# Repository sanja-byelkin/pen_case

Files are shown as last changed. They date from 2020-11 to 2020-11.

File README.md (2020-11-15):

# pen_case
OpenSCAD parametric pen case

I broke my favorite pen in my bag, so decided to make individual pen cases for my best pens.

This project create pen case by your description. If you unsure use the customizer in OpenSCAD.

You will need this library for threads to build it https://dkprojects.net/openscad-threads/ . Put it one level up or fix very first "include" derective.

For more details see manual.html ( https://htmlpreview.github.io/?https://github.com/sanja-byelkin/pen_case/blob/main/manual.html ).

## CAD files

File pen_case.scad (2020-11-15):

include <../threads.scad>

/* [Print Settings] */
// Cyrcles interpolation
FINESS=80; //[50:500]
// Tollerance of the printer (width of cuts and increasing goven dimentions)
TOLLERANCE= 0.3; // [0.1, 0.2, 0.3, 0.4, 0.5]
// nozzle diameter
NOZZEL_D= 0.4; // [0.2, 0.3, 0.4, 0.5, 0.6, 0.7, 0.8, 0.9, 1]
//Build case or pen "models"
PRESENT="case"; // ["case","model"]
//PRESENT="model";

/* [Case] */
// Minimum Case length (0 - automatic)
CASE_MIN_LENGTH= 0;
// Minimum case "diameter" (0 - automatic)
CASE_MIN_D= 0;
// Minimum thickness of top and bottom
CASE_TOP_BOTTOM_WALL_MIN= 1.6;
// Thikness of side walls
CASE_WALL= 1.2; // [3, 2.4, 2, 1.8, 1.6, 1.2]
// Latch pin hight
LATCH_PIN_H= 2; // [3, 2.4, 2, 1.8, 1.6, 1.2]
// Latch hight
LATCH_H= 2.4; // [3, 2.4, 2, 1.8, 1.6, 1.2]
// Latch final depth (starts with thikness of the case wall)
LATCH_DEPTH= 2.4; // [3, 2.4, 2, 1.8, 1.6, 1.2]
// Case close in turns
CASE_TURN= 2/3; // [0.3333333, 0.6666666, 0.5, 1, 1.5, 2, 3]
// Case thread width
CASE_TR_W= 2.5; // [2.5, 3, 3.5, 4, 4.5, 5]
// Case thread length (not 0 - automatic length and multiplier)
CASE_TR_L= 0; // [0:100]
// Case faces
CASE_N= 3; // [3, 4, 5, 6, 7, 8, 9, 10]
// Case corners rounding
CASE_ROUNDING= 9; // [0, 1, 1.5, 2, 2.5, 3, 4, 5, 6, 8, 9, 10, 11, 12]
// Case corners rounding mode
CASE_ROUNDING_MODE="2.5d"; // ["sharp", "2d", "3d", "2.5d"]
// Case thread starts multiplier (starts = faces*multiplier)
CASE_TR_NN= 1; // [1, 2, 3, 4]
// Case thread space multiplier (as above but space)
CASE_TR_SPACE_RATIO= 1.5; // [1, 1.3333333, 1.5, 1.6666666, 2]
// So many pen will be wisible from the case to take it out
CASE_TAKE= 9;
// Latch maximum length
LATCH_MAX_L= 15;
// Generate latch supports
LATCH_SUPPORT= true;

/* [text] */
// Vertical text (empty string to no text)
VTEXT_TEXT= "Noodler's Boston Safety";
// Vertical text font
VTEXT_FONT= "Liberation Sans;style=bold";
// Vertical text size
VTEXT_SIZE= 7.8;
// Vertical text depth
VTEXT_DEPTH= 0.6;
// Vertical text skip ratio (1-each face, 2-each second ...)
VTEXT_RATIO= 1; // [1, 2, 3, 4, 5, 6, 7, 8, 9, 10]
// Vertical text turn (top-bottom / bottom-top)
VTEXT_TURN=false; // [true, false]
// Top/bottom text (empty string to no text)
TBTEXT_TEXT= "Boston";
// Top/bottom text font
TBTEXT_FONT= "Liberation Sans;style=bold";
// Top/bottom text size
TBTEXT_SIZE= 6;
// Top/bottom text turn angle
TBTEXT_ANGLE= 30;
// Top/bottom text depth
TBTEXT_DEPTH= 0.6;

/* [Pen] */

// First (top) cylinder diameter
PEN_1_D=12.5;
// First cylinder length (0 - no section)
PEN_1_L=8.2;
// First clip overhang (0 - no clip)
PEN_1_CLIP_DD=0;
// First clip width
PEN_1_CLIP_W=0;
// Second cylinder diameter
PEN_2_D=13;
// Second cylinder length (0 - no section)
PEN_2_L=40;
// Second clip overhang (0 - no clip)
PEN_2_CLIP_DD=4;
// Second clip width
PEN_2_CLIP_W=6;
// Third cylinder diameter
PEN_3_D=13;
// Third cylinder length (0 - no section)
PEN_3_L=2.5;
// Third clip overhang (0 - no clip)
PEN_3_CLIP_DD=0;
// Third clip width
PEN_3_CLIP_W=0;
// Fourth cylinder diameter
PEN_4_D=11;
// Fourth cylinder length (0 - no section)
PEN_4_L=36;
// Fourth clip overhang (0 - no clip)
PEN_4_CLIP_DD=0;
// Fourth clip width
PEN_4_CLIP_W=0;
// Fifth cylinder diameter
PEN_5_D=13;
// Fifth cylinder length (0 - no section)
PEN_5_L=56.5;
// Fifth clip overhang (0 - no clip)
PEN_5_CLIP_DD=0;
// Fifth clip width
PEN_5_CLIP_W=0;
// Sixth cylinder diameter
PEN_6_D=11;
// Sexth cylinder length (0 - no section)
PEN_6_L=12;
// Sexth clip overhang (0 - no clip)
PEN_6_CLIP_DD=0;
// Fexth clip width
PEN_6_CLIP_W=0;


/* [Hidden] */

LATCH_W= CASE_WALL;
$fn= FINESS;

/*******************************
    Some known pen model data
********************************/
/*
// Lamy 2000
// First (top) cylinder diameter
PEN_1_D=10;
// First cylinder length (0 - no section)
PEN_1_L=3.3;
// First clip overhang (0 - no clip)
PEN_1_CLIP_DD=0;
// First clip width
PEN_1_CLIP_W=0;
// Second cylinder diameter
PEN_2_D=13.6;
// Second cylinder length (0 - no section)
PEN_2_L=38.3;
// Second clip overhang (0 - no clip)
PEN_2_CLIP_DD=2.8;
// Second clip width
PEN_2_CLIP_W=5.1;
// Third cylinder diameter
PEN_3_D=14.3;
// Third cylinder length (0 - no section)
PEN_3_L=22.8;
// Third clip overhang (0 - no clip)
PEN_3_CLIP_DD=0;
// Third clip width
PEN_3_CLIP_W=0;
// Fourth cylinder diameter
PEN_4_D=13.3;
// Fourth cylinder length (0 - no section)
PEN_4_L=74.4;
// Fourth clip overhang (0 - no clip)
PEN_4_CLIP_DD=0;
// Fourth clip width
PEN_4_CLIP_W=0;
// Fifth cylinder diameter
PEN_5_D=0;
// Fifth cylinder length (0 - no section)
PEN_5_L=0;
// Fifth clip overhang (0 - no clip)
PEN_5_CLIP_DD=0;
// Fifth clip width
PEN_5_CLIP_W=0;
// Sixth cylinder diameter
PEN_6_D=0;
// Sexth cylinder length (0 - no section)
PEN_6_L=0;
// Sexth clip overhang (0 - no clip)
PEN_6_CLIP_DD=0;
// Fexth clip width
PEN_6_CLIP_W=0;
*/
/*
// Lamy Safari
// First (top) cylinder diameter
PEN_1_D=13;
// First cylinder length (0 - no section)
PEN_1_L=3.5;
// First clip overhang (0 - no clip)
PEN_1_CLIP_DD=0;
// First clip width
PEN_1_CLIP_W=0;
// Second cylinder diameter
PEN_2_D=14.7;
// Second cylinder length (0 - no section)
PEN_2_L=56.4;
// Second clip overhang (0 - no clip)
PEN_2_CLIP_DD=4;
// Second clip width
PEN_2_CLIP_W=13.5;
// Third cylinder diameter
PEN_3_D=14.7;
// Third cylinder length (0 - no section)
PEN_3_L=5.5;
// Third clip overhang (0 - no clip)
PEN_3_CLIP_DD=0;
// Third clip width
PEN_3_CLIP_W=0;
// Fourth cylinder diameter
PEN_4_D=12.5;
// Fourth cylinder length (0 - no section)
PEN_4_L=73;
// Fourth clip overhang (0 - no clip)
PEN_4_CLIP_DD=0;
// Fourth clip width
PEN_4_CLIP_W=0;
// Fifth cylinder diameter
PEN_5_D=11.7;
// Fifth cylinder length (0 - no section)
PEN_5_L=1.6;
// Fifth clip overhang (0 - no clip)
PEN_5_CLIP_DD=0;
// Fifth clip width
PEN_5_CLIP_W=0;
// Sixth cylinder diameter
PEN_6_D=0;
// Sexth cylinder length (0 - no section)
PEN_6_L=0;
// Sexth clip overhang (0 - no clip)
PEN_6_CLIP_DD=0;
// Fexth clip width
PEN_6_CLIP_W=0;
*/
/*
// Opus 88 KOLORO DEMO
// First (top) cylinder diameter
PEN_1_D=16.3;
// First cylinder length (0 - no section)
PEN_1_L=7.7;
// First clip overhang (0 - no clip)
PEN_1_CLIP_DD=0;
// First clip width
PEN_1_CLIP_W=0;
// Second cylinder diameter
PEN_2_D=16.5;
// Second cylinder length (0 - no section)
PEN_2_L=42.3;
// Second clip overhang (0 - no clip)
PEN_2_CLIP_DD=4.8;
// Second clip width
PEN_2_CLIP_W=8;
// Third cylinder diameter
PEN_3_D=16.5;
// Third cylinder length (0 - no section)
PEN_3_L=13.5;
// Third clip overhang (0 - no clip)
PEN_3_CLIP_DD=0;
// Third clip width
PEN_3_CLIP_W=0;
// Fourth cylinder diameter
PEN_4_D=15;
// Fourth cylinder length (0 - no section)
PEN_4_L=83.3;
// Fourth clip overhang (0 - no clip)
PEN_4_CLIP_DD=0;
// Fourth clip width
PEN_4_CLIP_W=0;
// Fifth cylinder diameter
PEN_5_D=0;
// Fifth cylinder length (0 - no section)
PEN_5_L=0;
// Fifth clip overhang (0 - no clip)
PEN_5_CLIP_DD=0;
// Fifth clip width
PEN_5_CLIP_W=0;
// Sixth cylinder diameter
PEN_6_D=0;
// Sexth cylinder length (0 - no section)
PEN_6_L=0;
// Sexth clip overhang (0 - no clip)
PEN_6_CLIP_DD=0;
// Fexth clip width
PEN_6_CLIP_W=0;
*/
/*
// Noodler's Konrad
// First (top) cylinder diameter
PEN_1_D=12;
// First cylinder length (0 - no section)
PEN_1_L=6.9;
// First clip overhang (0 - no clip)
PEN_1_CLIP_DD=0;
// First clip width
PEN_1_CLIP_W=0;
// Second cylinder diameter
PEN_2_D=14;
// Second cylinder length (0 - no section)
PEN_2_L=39.1;
// Second clip overhang (0 - no clip)
PEN_2_CLIP_DD=4;
// Second clip width
PEN_2_CLIP_W=6;
// Third cylinder diameter
PEN_3_D=14.5;
// Third cylinder length (0 - no section)
PEN_3_L=13;
// Third clip overhang (0 - no clip)
PEN_3_CLIP_DD=0;
// Third clip width
PEN_3_CLIP_W=0;
// Fourth cylinder diameter
PEN_4_D=12;
// Fourth cylinder length (0 - no section)
PEN_4_L=74;
// Fourth clip overhang (0 - no clip)
PEN_4_CLIP_DD=0;
// Fourth clip width
PEN_4_CLIP_W=0;
// Fifth cylinder diameter
PEN_5_D=0;
// Fifth cylinder length (0 - no section)
PEN_5_L=0;
// Fifth clip overhang (0 - no clip)
PEN_5_CLIP_DD=0;
// Fifth clip width
PEN_5_CLIP_W=0;
// Sixth cylinder diameter
PEN_6_D=0;
// Sexth cylinder length (0 - no section)
PEN_6_L=0;
// Sexth clip overhang
PEN_6_CLIP_DD=0;
// Fexth clip width
PEN_6_CLIP_W=0;
*/
/*
// Noodler's Ahab
// First (top) cylinder diameter
PEN_1_D=11;
// First cylinder length (0 - no section)
PEN_1_L=6.5;
// First clip overhang (0 - no clip)
PEN_1_CLIP_DD=0;
// First clip width
PEN_1_CLIP_W=0;
// Second cylinder diameter
PEN_2_D=15.1;
// Second cylinder length (0 - no section)
PEN_2_L=41.5;
// Second clip overhang (0 - no clip)
PEN_2_CLIP_DD=5.5;
// Second clip width
PEN_2_CLIP_W=8;
// Third cylinder diameter
PEN_3_D=15.2;
// Third cylinder length (0 - no section)
PEN_3_L=12;
// Third clip overhang (0 - no clip)
PEN_3_CLIP_DD=0;
// Third clip width
PEN_3_CLIP_W=0;
// Fourth cylinder diameter
PEN_4_D=14;
// Fourth cylinder length (0 - no section)
PEN_4_L=69.2;
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

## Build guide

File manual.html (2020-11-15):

# Installation

1. Install (if not done) OpenSCAD (https://www.openscad.org/)
2. Clone this repository or copy pen_case.scad in a directory pen_case
3. Copy from https://dkprojects.net/openscad-threads/ threads.scad in a directory above pen_case.

# Creating a pen case

You can use OpenSCAD customizer or just change variables at the beginning of the pen_case.scad manually if OpenSCAD editor (or any other text editor).

## Print settings

FINESS

How many faces will have cylinder approximation. More mean smoother model but longer render time (50-80 is enough for useful cases).

TOLLERANCE

A "gap" between real and printed object. depends on 3d printer quality and printing speed

NOZZEL_D

Diameter of your printer nozzel, now used only to print latch support.

PRESENT

Build pen "case" or pen "model".

## Case parameters

CASE_MIN_LENGTH and CASE_MIN_D

You can use non 0 values if you want to build same size cases for different pens.

CASE_TOP_BOTTOM_WALL_MIN and CASE_WALL

Minimal thickness of the walls.

LATCH_PIN_H

Lutch pin hight. 2.4-1.6 looks the best values

LATCH_H and LATCH_DEPTH

Lutch hand parameters (hight and depth). I do not recommend use LATCH_H bigger then LATCH_DEPTH and both less then 1.6 and more then 3. Top of the hand will be CASE_WALL depth and LATCH_DEPTH will not be less then CASE_WALL.

CASE_TURN

How many turns minimum needed to open this case.

CASE_TR_W

Width of the case thread.

CASE_TR_L

(Minimum) length of the case thread. If 0 will be calculated automatically

CASE_N

Number of faces of this case. Also it is minimum number of thread starts

CASE_ROUNDING

Radius of case rounding. Used if CASE_ROUNDING_MODE is not "sharp"

CASE_ROUNDING_MODE

"sharp"

No roundings.

"2d"

Only side walls.

"3d"

Side walls top and bottom (difficult to print).

"2.5d"

Side walls with CASE_ROUNDING radius and top and bottom with CASE_WALL.

CASE_TR_NN

How many thread starts do per "face". If it is not 1 can be difficult to close case correctly.

CASE_TR_SPACE_RATIO

1 mean as dense thread is possible, more then 1 makes spaces in threads. With small number of faces can be used to make longer and "steeper" thread.

CASE_TAKE

How much pen you will see after opening this case. Depend on how much you need to take the pen from the case.

LATCH_MAX_L

Max latch length, used to limit length and keep the latches stiff.

LATCH_SUPPORT

Construct or not the latches support for 3D printer

## Text setup

Probably fonts and its sizes depend on a computer setup, so just experiment.

## Pen "model" description

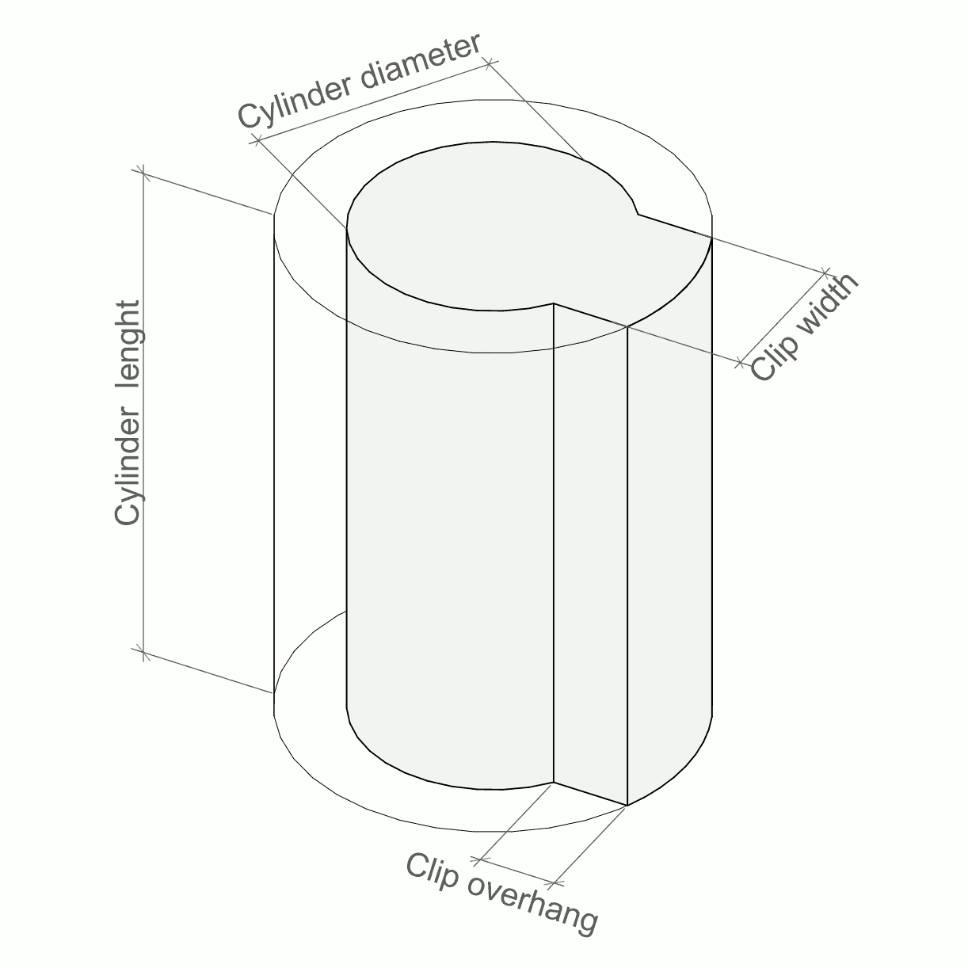
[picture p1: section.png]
Section description
 Pen described as sequence of sections. Each section described with numbered from 1 to 6 sets of variable

PEN_n_D

Cylinder Diameter

PEN_n_L

Cylinder Length (section skipped if 0)

PEN_n_CLIP_DD

Clip overhang (section will be simple cylinder if 0)

PEN_n_CLIP_W

Clip width

You can see "model" of the pen if you change variable PRESENT to "model" and click on a "preview".

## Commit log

2020-11-06 Old code removed.
    [pen_case.scad]
2020-11-06 pen data marked
    [pen_case.scad]
2020-11-06 Corners rounding added
    [pen_case.scad]
2020-11-07 fixed rounding
    [pen_case.scad]
2020-11-07 More fixes for rounding
    [pen_case.scad]
2020-11-08 Added differential rounding ("2.5d")
    [pen_case.scad]
2020-11-08 fixed comments
    [pen_case.scad]
2020-11-11 Allign clop cut with "start" of "circle" of the case shape.
    [pen_case.scad]
2020-11-11 Keep latch code together
    [pen_case.scad]
2020-11-12 Fix problem of latches if thay are higer than wider.
    [pen_case.scad]
2020-11-15 parameter description fix and clean up
    [pen_case.scad]
